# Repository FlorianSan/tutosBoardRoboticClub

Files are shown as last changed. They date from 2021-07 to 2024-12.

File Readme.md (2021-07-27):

# Carte tutos club Robot

Carte électronique pour apprendre les bases de l'électronique et de la programmation au nouveaux membres du club robotique.

Cette carte devrait être suffisamment compacte et pratique pour être emportée chez soi.

Sujets:

+ LEDs
+ boutons, pullups, ...
+ potentiomètre: analogique
+ PWM
+ UART
+ I2C
+ Encoder
+ Asservissement d'un moteur

Carte compatible Nucleo F411, F401RE. (et peut-être d'autres)

# Getting started

Le plus simple pour démarrer est d'installer VSCode, et l'extension PlateformIO.

Créer un projet pour la carte que vous utilisez (par exemple : ST Nucleo F401RE), avec le framwork Arduino.

Ajouter ceci au fichier `platformio.ini` pour activer l'UART6 qui va permettre de communiquer avec l'ATtiny1616 :

`build_flags = -D ENABLE_HWSERIAL6`

# Pinout

## Nucleo

| Pin | Signal |
|-----|---|
|PA0  |BTN1 (B1)  |
|PA1  |BTN2 (B2)  |
|PA4  |BUZZ |
|PA8  |Enc1A |
|PA9  |Enc1B |
|PA10 |Display_CLK|
|PA11 |UART6_TX |
|PA12 |UART6_RX |
|PA15 |MotB |
|PB0  |POT |
|PB1  |LED1 |
|PB4  |SERVO1 |
|PB5  |SERVO2 |
|PB6  |Enc2A |
|PB7  |Enc2B |
|PB8  |SCL1 |
|PB9  |SDA1 |
|PB10 |MotA |
|PB12 |Attiny_link|
|PC4  |Display_DIO|
|PC8  |LED2 |
|PC9  |INT_TCA |

Les jumpers JP1 et JP2 connectent respectivement une résistance de pullup et de pulldown aux signaux BTN1 et BTN2.

Afin d'utiliser les servomoteurs ou le moteur, il faut alimenter la carte par le connecteur jack DC en 12V (12V sur le connecteur central, GND sur l'extérieur), et régler le jumper JP5 de la nucleo (à côté du bouton RESET) sur "E5V".
La led D19 devrait s'allumer.

## TCA9554

| Pin | Signal  |
|-----|---|
|P0 |D4 |
|P1 |D5 |
|P2 |D6 |
|P3 |D7 |
|P4 |D17 |
|P5 |D18 |
|P6 |SW6 (B3) |
|P7 |SW7 (B4) |

SW5 permet de régler un bit d'adresse (A0).

SW4 permet de connecter ou pas les pullups sur SDA et SCL.

La broche INT est connectée sur la broche PC9 de la nucleo.

Les broches d'adresses A1 et A2 sont connectés à GND.

datasheet : [http://www.ti.com/lit/ds/symlink/tca9554.pdf](http://www.ti.com/lit/ds/symlink/tca9554.pdf)

## Display

L'afficheur 7segments 4 digits est commandé par un TM1637.

datasheet : [https://www.mcielectronics.cl/website_MCI/static/documents/Datasheet_TM1637.pdf](https://www.mcielectronics.cl/website_MCI/static/documents/Datasheet_TM1637.pdf)

## Driver moteur

Le driver moteur est un BD62120AEFJ.

datasheet : [https://docs.rs-online.com/a300/0900766b816747fb.pdf](https://docs.rs-online.com/a300/0900766b816747fb.pdf)

## ATtiny 1616

:warning: Si vous regardez ça, vous savez ce que vous faites !

| Pin | Signal |
|-----|---|
|PA0  |UPDI |
|PA2  |Attiny_link|
|PA4  |D10 |
|PA5  |D9 |
|PA6  |D8 |
|PA7  |D16 |
|PB0  |D11 |
|PB1  |D13 |
|PB2  |UART6_RX |
|PB3  |UART6_TX |
|PB4  |D14 |
|PB5  |D15 |
|PC0  |D12 |
|PC1  |AtPot |
|PC2  |AtLight |

:warning: UART6_RX et UART6_TX sont les signaux de la nucleo, qui correspondent donc respectivement à TX et RX de l'ATtiny.

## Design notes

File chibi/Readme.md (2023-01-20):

# ChibiOS example

Install the compiler, the debugger, and the stlink tools:

`sudo apt-get install gcc-arm-none-eabi gdb-multiarch stlink-tools`

Fetch ChibiOS and the STM32 pin data:

`git submodule update --init --recursive`

Build the firmware:

`make`

Flash the MCU:

`make flash`

The `ext/boardGen.pl` tool is extracted from https://github.com/alex31/chibios_enac_various_common.git.
It uses data from https://github.com/STMicroelectronics/STM32_open_pin_data to generate the `board.h` file from a short `board.cfg`.

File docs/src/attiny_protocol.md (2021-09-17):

# Attiny protocol

The Attiny1616 featured in the tuto board controls 9 leds, and has 2 inputs : a potentiometer and a phototransistor, acting as light sensor.

The protocol documented here allows you to interact with the Attiny.

Packets sent by the nucleo to the Attiny will be called **Tx packets**. Those sent by the Attiny to the nucleo will be called **Rx packets**.

## Message format

All messages have the same format :

<table>
<tr>
<td>STX</td>
<td>LEN</td>
<td>PAYLOAD[...]</td>
<td>CHK</td>
</tr>
</table>

**STX**  
Start of the packet. STX=0xFF.

**LEN**  
Byte size of the PAYLOAD and CHK field.

**PAYLOAD**  
See Tx packets and Rx Packets.

**CHK**  
Checksum for the packet.
CHK = ~(LEN + PAYLOAD[0] + … + PAYLOAD[N])

## Tx packets

Payload of Tx packets is made of a 1 byte instruction optionally followed by parameters.

<table>
<tr>
<td>STX</td>
<td>LEN</td>
<td>INSTRCTION</td>
<td>PARAM 1</td>
<td>...</td>
<td>PARAM N</td>
<td>CHK</td>
</tr>
</table>

The instructions are:

+ **PING**  
  Ping the Attiny.  
  + Value: **0x01**
  + Parameters: no parameters
  + Answer: PONG message.

+ **READ**  
  Request the values of *count* registers, starting at *address*.  
  + Value: **0x02**
  + Parameters: Address (1byte), count (1byte)
  + Answer: REG message.

+ **WRITE**  
  Write the *values* at registers starting at *address*. The register address is auto-incremented.  
  + Value: **0x03**
  + Parameters: address, value1, value2, …
  + Answer: no answer

## Rx packets
Payload of Rx packets is made of a 1 byte identifier optionally followed by data.

+ **PONG**
  + Value: 0x11
  + Data: no data

+ **REG**
  + Value: 0x12
  + Data: values

+ **CONTINUOUS**
  + Value: 0x13
  + Data: 2 bytes defined as follow:

<table>
<tr>
<td>data_id[1:0]</td>
<td bgcolor="gray">RESERVED</td>
<td>data[9:8]</td>
</tr>
<tr>
<td colspan="3" style="text-align:center">data[7:0]</td>
</tr>
</table>

Where data_id identify the nature of the data:

+ 0x0: potentiometer value
+ 0x1: light value
+ 0x2: leds status

The data itself spans over 10 bits for potentiometer and light values, and 9 bits for leds status.

## Registers description

|Name |Address|Access|
|---|---|---|
|POT_L  |0X00 |R |
|POT_H  |0X01 |R |
|LIGHT_L|0X02 |R |
|LIGHT_H|0X03 |R |
|LEDS_L |0X04 |RW |
|LEDS_H |0X05 |RW |
|MODE |0X06 |RW |

### POT

10 bits potentiometer value.

<div>
    <div style="width: 60px; float: left;">
        POT_H<br/>
        POT_L
    </div>
    <div>
        <table>
        <tr>
        <td bgcolor="gray">RESERVED</td>
        <td>POT[9:8]</td>
        </tr>
        <tr>
        <td colspan="2" style="text-align:center">POT[7:0]</td>
        </tr>
        </table>
     </div>
</div>

### LIGHT

10 bits light value.

<div>
    <div style="width: 60px; float: left;">
        LIGHT_H<br/>
        LIGHT_L
    </div>
    <div>
        <table>
        <tr>
        <td bgcolor="gray">RESERVED</td>
        <td>LIGHT[9:8]</td>
        </tr>
        <tr>
        <td colspan="2" style="text-align:center">LIGHT[7:0]</td>
        </tr>
        </table>
     </div>
</div>

### LEDS

State of the leds. 0 is OFF, 1 is ON.  
Default value: 0

<div>
    <div style="width: 60px; float: left;">
        LEDS_H<br/>
        LEDS_L
    </div>
    <div>
        <table>
        <tr>
        <td bgcolor="gray">RESERVED</td>
        <td>LEDS[8]</td>
        </tr>
        <tr>
        <td colspan="2" style="text-align:center">LEDS[7:0]</td>
        </tr>
        </table>
     </div>
</div>

### MODE

+ **POTC**: if set, the Attiny will send CONTINUOUS potentiometer data. **Default 0**.
+ **LIGHTC**: if set, the Attiny will send CONTINUOUS light data. **Default 0**.
+ **LEDSC**: if set, the Attiny will send CONTINUOUS leds data. **Default 0**.
+ **CFREQ**: frequency at which CONTINUOUS messages will be sent.
+ **LEDSMODE**: Leds command mode.

<table>
<tr>
<td>POTC</td>
<td>LIGHTC</td>
<td>LEDSC</td>
<td>CFREQ[1:0]</td>
<td>LEDSMODE[2:0]</td>
</table>

**bitfields values:**

<div style="display:flex;">
    <div style="flex:1;">
        CFREQ[1:0]   
        <ul>
        <li>0x0: 50ms (20Hz)</li>
        <li>0x1: 100ms (10Hz) <strong>default</strong></li>
        <li>0x2: 200ms (5Hz)</li>
        <li>0x3: 500ms (2Hz)</li>
        </ul>
    </div>
    <div style="flex:1">
        LEDSMODE[2:0]  
        <ul>
        <li>0x0: MANUAL: write to the LEDS register to command the leds.</li>
        <li>0x1: Pot value: leds reflect potentiometer value. <strong>default</strong></li>
        <li>0x2: Light value: leds reflect light value.</li>
        <li>0x3: Pot speed: not implemented</li>
        <li>0x4: Light speed: not implemented</li>
        </ul>
     </div>
</div>

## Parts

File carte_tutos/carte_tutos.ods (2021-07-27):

Qty | Reference(s) | Value | LibPart | Footprint | Price | Total
1 | BZ1 | Buzzer | Device:Buzzer | Buzzer_Beeper:MagneticBuzzer_ProSignal_ABT-410-RC | 0.4 | 0.4
2 | C1, C2 | 100p | Device:C | Capacitor_SMD:C_0603_1608Metric_Pad1.08x0.95mm_HandSolder | 0.04 | 0.08
4 | C3, C5, C7, C8 | 100n | Device:C | Capacitor_SMD:C_0603_1608Metric_Pad1.08x0.95mm_HandSolder | 0.04 | 0.16
2 | C4, C6 | 100u | Device:C | Capacitor_Tantalum_SMD:CP_EIA-6032-28_Kemet-C_Pad2.25x2.35mm_HandSolder | 0.8 | 1.6
18 | D1, D2, D4, D5, D6, D7, D8, D9, D10, D11, D12, D13, D14, D15, D16, D17, D18, D19 | LED | Device:LED | LED_SMD:LED_0603_1608Metric_Pad1.05x0.95mm_HandSolder | 0.07 | 1.26
1 | D3 | D_Schottky | Device:D_Schottky | Diode_SMD:D_SOD-123F | 0.364 | 0.364 | https://fr.rs-online.com/web/p/redresseurs-et-diodes-schottky/0485521
4 | J1, J2, J6, J8 | Conn_01x03_Male | Connector:Conn_01x03_Male | Connector_PinHeader_2.54mm:PinHeader_1x03_P2.54mm_Vertical | 0.1 | 0.4
1 | J3 | Barrel_Jack | Connector:Barrel_Jack |  | 0.353 | 0.353 | https://fr.rs-online.com/web/p/connecteurs-d-alimentation-dc/0448376
1 | J4 | Conn_01x04_Male | Connector:Conn_01x04_Male | Connector_PinHeader_2.54mm:PinHeader_1x04_P2.54mm_Vertical | 0.1 | 0.1
2 | J5, J7 | Conn_01x02_Male | Connector:Conn_01x02_Male | Connector_PinHeader_2.54mm:PinHeader_1x02_P2.54mm_Vertical | 0.1 | 0.2
2 | JP1, JP2 | Jumper | Device:Jumper | Connector_PinHeader_2.54mm:PinHeader_1x02_P2.54mm_Vertical | 0.1 | 0.2
1 | Q1 | SFH_3410-Z | tutoLib:SFH_3410-Z | tutoFp:SFH_3410 | 0.4 | 0.4 | https://fr.rs-online.com/web/p/phototransistors/0539864
10 | R1, R4, R5, R7, R9, R13, R14, R20, R21, R39 | 100 | Device:R_Small | Resistor_SMD:R_0603_1608Metric_Pad0.98x0.95mm_HandSolder | 0.02 | 0.2
17 | R2, R3, R19, R22, R27, R28, R29, R30, R31, R32, R33, R34, R35, R36, R37, R40, R41 | 390 | Device:R | Resistor_SMD:R_0603_1608Metric_Pad0.98x0.95mm_HandSolder | 0.02 | 0.34
6 | R6, R8, R11, R12, R17, R26 | 10k | Device:R | Resistor_SMD:R_0603_1608Metric_Pad0.98x0.95mm_HandSolder | 0.02 | 0.12
1 | R10 | 220 | Device:R | Resistor_SMD:R_0603_1608Metric_Pad0.98x0.95mm_HandSolder | 0.02 | 0.02
2 | R15, R16 | 2.2K | Device:R | Resistor_SMD:R_0603_1608Metric_Pad0.98x0.95mm_HandSolder | 0.02 | 0.04
1 | R18 | 1k | Device:R | Resistor_SMD:R_0603_1608Metric_Pad0.98x0.95mm_HandSolder | 0.02 | 0.02
1 | R23 | 2k | Device:R | Resistor_SMD:R_0603_1608Metric_Pad0.98x0.95mm_HandSolder | 0.02 | 0.02
1 | R38 | 470 | Device:R_Small | Resistor_SMD:R_0603_1608Metric_Pad0.98x0.95mm_HandSolder | 0.02 | 0.02
2 | RV1, RV2 | R_POT | Device:R_POT | Potentiometer_THT:Potentiometer_Bourns_PTV09A-1_Single_Vertical | 0.73 | 1.46 | https://fr.rs-online.com/web/p/potentiometres/1814488
1 | SW1 | Rotary_Encoder_Switch | Device:Rotary_Encoder | Rotary_Encoder:RotaryEncoder_Alps_EC12E_Vertical_H20mm | 0.77 | 0.77 | https://fr.rs-online.com/web/p/encodeurs-rotatifs-mecaniques/6234221
4 | SW2, SW3, SW6, SW7 | SW_Push | Switch:SW_Push | Button_Switch_SMD:SW_SPST_EVQPE1 | 0.493 | 1.972 | https://fr.rs-online.com/web/p/interrupteurs-tactiles/3786325/
1 | SW4 | SW_DIP_x02 | Switch:SW_DIP_x02 | Button_Switch_THT:SW_DIP_SPSTx02_Slide_9.78x7.26mm_W7.62mm_P2.54mm | 0.4 | 0.4
1 | SW5 | SW_SPDT | Switch:SW_SPDT | Button_Switch_SMD:SW_SPDT_PCM12 | 0.94 | 0.94
1 | U1 | TM1637 | tutoLib:TM1637 | Package_SO:SOP-20_7.5x12.8mm_P1.27mm | 1 | 1
1 | U2 | CA56-12EWA | Display_Character:CA56-12EWA | Display_7Segment:CA56-12EWA | 0.6 | 0.6
1 | U3 | BD62120AEFJ | tutoLib:BD62120AEFJ | Package_SO:HTSOP-8-1EP_3.9x4.9mm_P1.27mm_EP2.4x3.2mm | 2.525 | 2.525 | https://fr.rs-online.com/web/p/drivers-de-moteur/1780653
1 | U4 | NUCLEO64-F411RE | MCU_Module:NUCLEO64-F411RE | Module:ST_Morpho_Connector_144_STLink | 14.87 | 14.87 | https://fr.rs-online.com/web/p/outils-de-developpement-pour-microcontroleurs/8029425/
1 | U5 | TCA9554DBQ | Interface_Expansion:TCA9554DBQ | Package_SO:SSOP-16_3.9x4.9mm_P0.635mm | 1.742 | 1.742 | https://fr.rs-online.com/web/p/expandeurs-e-s/1330708/
1 | U6 | ATtiny1616-S | MCU_Microchip_ATtiny:ATtiny1616-S | Package_SO:SOIC-20W_7.5x12.8mm_P1.27mm | 1 | 1 | https://fr.rs-online.com/web/p/microcontroleurs/1936207
1 |  | Jack mâle |  |  | 2.17 | 2.17 | https://fr.rs-online.com/web/p/connecteurs-d-alimentation-dc/1389405
1 |  | PCB |  |  | 5 | 5
 |  |  |  |  |  | 40.746

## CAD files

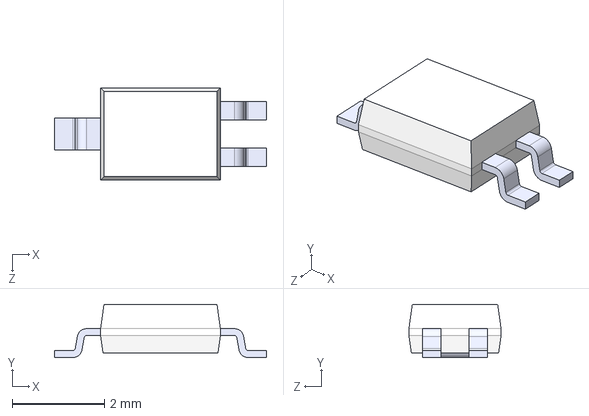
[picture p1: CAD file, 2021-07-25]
carte_tutos/SFH_3410-Z.step
4.60 x 1.15 x 2.00 mm

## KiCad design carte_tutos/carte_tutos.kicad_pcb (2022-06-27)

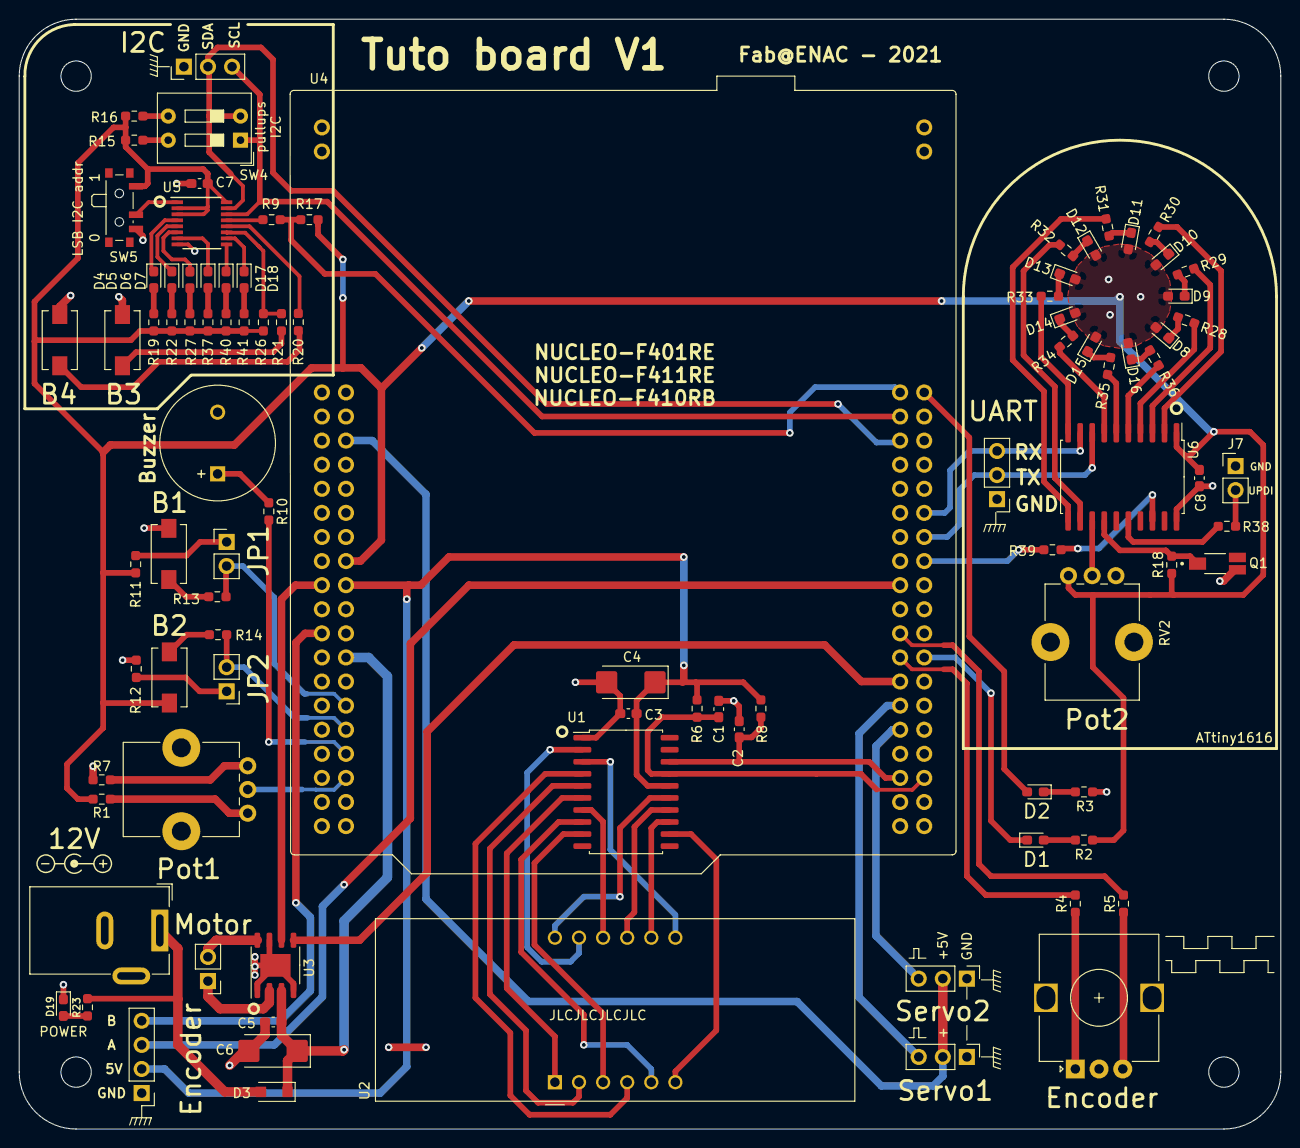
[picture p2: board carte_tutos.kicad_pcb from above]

Board: 2 copper layers, 133.0 x 117.0 mm, 93 parts (0 on the bottom side), 97 nets.

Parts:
BZ1: Buzzer; MagneticBuzzer_ProSignal_ABT-410-RC
C1, C2: 100p; C_0603_1608Metric_Pad1.08x0.95mm_HandSolder
C3, C5, C7, C8: 100n; C_0603_1608Metric_Pad1.08x0.95mm_HandSolder
C4, C6: 100u; CP_EIA-6032-28_Kemet-C_Pad2.25x2.35mm_HandSolder
D1, D2, D4, D5, D6, D7, D8, D9, D10, D11, D12, D13, D14, D15, D16, D17, D18, D19: LED; LED_0603_1608Metric_Pad1.05x0.95mm_HandSolder
D3: D_Schottky; D_SOD-123F
J1, J2, J6, J8: Conn_01x03_Male; PinHeader_1x03_P2.54mm_Vertical
J3: Barrel_Jack; BarrelJack_Wuerth_6941xx301002
J4: Conn_01x04_Male; PinHeader_1x04_P2.54mm_Vertical
J5, J7: Conn_01x02_Male; PinHeader_1x02_P2.54mm_Vertical
JP1, JP2: Jumper; PinHeader_1x02_P2.54mm_Vertical
Q1: SFH_3410-Z; SFH_3410
R1, R4, R5, R7, R9, R13, R14, R20, R21, R39: 100; R_0603_1608Metric_Pad0.98x0.95mm_HandSolder
R2, R3, R19, R22, R27, R28, R29, R30, R31, R32, R33, R34, R35, R36, R37, R40, R41: 390; R_0603_1608Metric_Pad0.98x0.95mm_HandSolder
R6, R8, R11, R12, R17, R26: 10k; R_0603_1608Metric_Pad0.98x0.95mm_HandSolder
R10: 220; R_0603_1608Metric_Pad0.98x0.95mm_HandSolder
R15, R16: 2.2K; R_0603_1608Metric_Pad0.98x0.95mm_HandSolder
R18: 1k; R_0603_1608Metric_Pad0.98x0.95mm_HandSolder
R23: 2k; R_0603_1608Metric_Pad0.98x0.95mm_HandSolder
R38: 470; R_0603_1608Metric_Pad0.98x0.95mm_HandSolder
RV1, RV2: R_POT; Potentiometer_Bourns_PTV09A-1_Single_Vertical
SW1: Rotary_Encoder_Switch; RotaryEncoder_Alps_EC12E_Vertical_H20mm
SW2, SW3, SW6, SW7: SW_Push; SW_SPST_EVQPE1
SW4: SW_DIP_x02; SW_DIP_SPSTx02_Slide_9.78x7.26mm_W7.62mm_P2.54mm
SW5: SW_SPDT; SW_SPDT_PCM12
U1: TM1637; SOP-20_7.5x12.8mm_P1.27mm
U2: CA56-12EWA
U3: BD62120AEFJ; HTSOP-8-1EP_3.9x4.9mm_P1.27mm_EP2.4x3.2mm
U4: NUCLEO64-F411RE; ST_Morpho_Connector_64_STLink
U5: TCA9554DBQ; SSOP-16_3.9x4.9mm_P0.635mm
U6: ATtiny1616-S; SOIC-20W_7.5x12.8mm_P1.27mm

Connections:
+3V3: C7.1, C8.1, D8.2, D9.2, D10.2, D11.2, D12.2, D13.2, D14.2, D15.2, D16.2, R1.2, R2.2, R11.2, R15.1, R16.1, R17.1, R18.1, R19.1, R22.1, R26.1, R27.1, R37.1, R40.1, R41.1, RV2.1, SW3.1, SW5.1, U4.16, U5.2, U5.3, U5.16, U6.1
+5V: C3.1, C4.1, J4.2, R6.2, R8.2, U1.16, U4.18
+5VP: J1.2, J2.2, U4.6
+12V: C5.1, C6.1, D3.1, U3.3, U4.24
/AtLed1: R28.1, U6.4
/AtLed2: R29.1, U6.3
/AtLed3: R30.1, U6.2
/AtLed4: R31.1, U6.11
/AtLed5: R32.1, U6.12
/AtLed6: R33.1, U6.10
/AtLed7: R34.1, U6.7
/AtLed8: R35.1, U6.6
/AtLed9: R36.1, U6.5
/AtLight: Q1.1, R18.2, U6.14
/AtPot: RV2.2, U6.13
/GRID1: U1.15, U2.12
/GRID2: U1.14, U2.9
/GRID3: U1.13, U2.8
/GRID4: U1.12, U2.6
/UPDI: J7.2, R38.1
Attiny_link: R39.1, U4.54
BTN1: JP1.2, R13.1, U4.28
BTN2: JP2.2, R14.1, U4.30
BUZZ: R10.2, U4.32
Display_CLK: C2.2, R8.1, U1.18, U4.71
Display_DIO: C1.2, R6.1, U1.17, U4.72
Enc1A: R4.2, U4.61
Enc1B: R5.2, U4.59
Enc2A: J4.3, U4.55
Enc2B: J4.4, U4.21
GND: BZ1.2, C1.1, C2.1, C3.2, C4.2, C5.2, C6.2, C7.2, C8.2, D19.1, J1.1, J2.1, J3.2, J3.3, J4.1, J6.1, J7.1, J8.1, Q1.3, R3.2, R7.1, R12.2, RV2.3, SW1.C, SW2.1, SW5.3, SW6.2, SW7.2, U1.1, U3.1, U3.4, U3.7, U3.9, U4.8, U4.19, U4.20, U4.22, U4.47, U4.58, U4.70, U4.77, U4.78, U4.79, U4.80, U5.8, U6.20
INT_TCA: R9.2, R17.2, U4.39
LED1: D1.1, U4.62
LED2: D2.2, U4.40
MotA: U3.5, U4.63
MotB: U3.6, U4.17
unnamed: BZ1.1, R10.1
unnamed: D1.2, R2.1
unnamed: D2.1, R3.1
unnamed: D3.2, J3.1, R23.2
unnamed: D4.1, U5.4
unnamed: D4.2, R19.2
unnamed: D5.1, U5.5
unnamed: D5.2, R22.2
unnamed: D6.1, U5.6
unnamed: D6.2, R27.2
unnamed: D7.1, U5.7
unnamed: D7.2, R37.2
unnamed: D8.1, R28.2
unnamed: D9.1, R29.2
unnamed: D10.1, R30.2
unnamed: D11.1, R31.2
unnamed: D12.1, R32.2
unnamed: D13.1, R33.2
unnamed: D14.1, R34.2
unnamed: D15.1, R35.2
unnamed: D16.1, R36.2
unnamed: D17.1, U5.9
unnamed: D17.2, R40.2
unnamed: D18.1, U5.10
unnamed: D18.2, R41.2
unnamed: D19.2, R23.1
unnamed: J5.1, U3.2
unnamed: J5.2, U3.8
unnamed: JP1.1, R11.1
unnamed: JP2.1, R12.1
unnamed: R1.1, RV1.3
unnamed: R4.1, SW1.A
unnamed: R5.1, SW1.B
unnamed: R7.2, RV1.1
unnamed: R9.1, U5.13
unnamed: R13.2, SW2.2
unnamed: R14.2, SW3.2
unnamed: R15.2, SW4.4
unnamed: R16.2, SW4.3
unnamed: R20.1, SW7.1
unnamed: R20.2, U5.12
unnamed: R21.1, SW6.1
unnamed: R21.2, R26.2, U5.11
unnamed: R38.2, U6.16
unnamed: R39.2, U6.18
unnamed: SW5.2, U5.1
unnamed: U1.2, U2.11
unnamed: U1.3, U2.7
unnamed: U1.4, U2.4
unnamed: U1.5, U2.2
unnamed: U1.6, U2.1
unnamed: U1.7, U2.10
unnamed: U1.8, U2.5
unnamed: U1.9, U2.3
POT: RV1.2, U4.34
SCL1: J6.3, SW4.1, U4.41, U5.14
SDA1: J6.2, SW4.2, U4.43, U5.15
SERVO1: J1.3, U4.65
SERVO2: J2.3, U4.67
UART6_RX: J8.3, U4.50, U6.9
UART6_TX: J8.2, U4.52, U6.8

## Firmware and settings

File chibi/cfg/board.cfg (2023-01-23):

MCU_MODEL = STM32F401R(D-E)Tx
CHIBIOS_VERSION = 3.0

HEADER
/*
 * Board identifier.
 */
#define BOARD_TUTO_ENAC_ROBOTIQUE
#define BOARD_NAME                  "Tuto board ENAC Robotique V1"

/*
 * Board oscillators-related settings.
 * NOTE: LSE not fitted.
 */
#if !defined(STM32_LSECLK)
#define STM32_LSECLK                0U
#endif

#define STM32_LSEDRV                (3U << 3U)

#if !defined(STM32_HSECLK)
#define STM32_HSECLK                8000000U
#endif
#define STM32_HSE_BYPASS

/*
 * Board voltages.
 * Required for performance limits calculation.
 */
#define STM32_VDD                   300U

/*
 * MCU type as defined in the ST header.
 */
#define STM32F401xE

CONFIG


# PIN NAME PERIPH_TYPE AF_NUMBER or
# PIN NAME FUNCTION PP_or_OPENDRAIN PIN_SPEED PULL_RESISTOR INITIAL_LEVEL AF_NUMBER
# SPEED : SPEED_VERYLOW, SPEED_LOW, SPEED_MEDIUM, SPEED_HIGH
#
# DEFAULT AND SYS
# 
# 'SYS' => ['ALTERNATE', 'PUSHPULL', 'SPEED_HIGH', 'FLOATING', 'LEVEL_HIGH'],
# 'ADC' => ['ANALOG', 'PUSHPULL', 'SPEED_HIGH', 'FLOATING', 'LEVEL_LOW'],
# 'PWM' => ['ALTERNATE', 'PUSHPULL', 'SPEED_HIGH', 'FLOATING', 'LEVEL_LOW'],
# 'ICU' => ['ALTERNATE', 'PUSHPULL', 'SPEED_HIGH', 'FLOATING', 'LEVEL_HIGH'],
# 'I2C' => ['ALTERNATE', 'OPENDRAIN', 'SPEED_HIGH', 'PULLUP', 'LEVEL_HIGH'],
# 'SPI' => ['ALTERNATE', 'PUSHPULL', 'SPEED_HIGH', 'FLOATING', 'LEVEL_HIGH'],
# 'UART' => ['ALTERNATE', 'PUSHPULL', 'SPEED_HIGH', 'PULLUP', 'LEVEL_HIGH'],
# 'OTG' => ['ALTERNATE', 'PUSHPULL', 'SPEED_HIGH', 'FLOATING', 'LEVEL_HIGH'],
# 'ETH' => ['ALTERNATE', 'PUSHPULL', 'SPEED_HIGH', 'FLOATING', 'LEVEL_HIGH'],
# 'FSMC' => ['ALTERNATE', 'PUSHPULL', 'SPEED_HIGH', 'FLOATING', 'LEVEL_HIGH'],
# 'SDIO' => ['ALTERNATE', 'PUSHPULL', 'SPEED_HIGH', 'PULLUP', 'LEVEL_HIGH'],
# 'SDIOCK' => ['ALTERNATE', 'PUSHPULL', 'SPEED_HIGH', 'FLOATING', 'LEVEL_HIGH'],
# 'CAN' => ['ALTERNATE', 'PUSHPULL', 'SPEED_HIGH', 'FLOATING', 'LEVEL_HIGH'],
# 'DCMI' => ['ALTERNATE', 'PUSHPULL', 'SPEED_HIGH', 'FLOATING', 'LEVEL_HIGH'],
# 'LED' => ['OUTPUT', 'PUSHPULL', 'SPEED_VERYLOW', 'FLOATING', 'LEVEL_LOW'],
# 'PASSIVE' => ['INPUT', 'PUSHPULL', 'SPEED_VERYLOW', 'FLOATING', 'LEVEL_LOW']);


# SYSTEM
PA13    SWDIO       SYS     AF:SYS_JTMS-SWDIO
PA14    SWCLK       SYS     AF:SYS_JTCK-SWCLK
#PB03    SWO         SYS     AF:SYS_JTDO-SWO


#PC14    OSC32_IN    SYS RCC_OSC32_IN 
#PC15    OSC32_OUT   SYS RCC_OSC32_OUT
PH00    OSC_IN      SYS RCC_OSC_IN
PH01    OSC_OUT     SYS RCC_OSC_OUT


#DEFAULT
DEFAULT                 INPUT   PUSHPULL SPEED_VERYLOW PULLDOWN LEVEL_LOW  AF0

# LEDS
PA05    LED_GREEN   LED
PC08    LED2        LED
PB01    LED1        LED

# BUTTONS
PC13    BUTTON      INPUT PULLUP
PA00    BTN1        INPUT PULLUP
PA01    BTN2        INPUT PULLUP

# UART debug
PA02    USART2_TX   UART    AF:USART2_TX
PA03    USART2_RX   UART    AF:USART2_RX

# UART Attiny
PA11    USART6_TX   UART    AF:USART6_TX
PA12    USART6_RX   UART    AF:USART6_RX

# I2C
PB08	I2C_SCL		I2C	    AF:I2C1_SCL
PB09	I2C_SDA		I2C	    AF:I2C1_SDA

# TCA interrupt input
PC09    TCA_INT     INPUT   FLOATING

# potentiometre
PB00    POTAR       ADC     ADC1_IN8

# servos
PB04    SERVO1      PWM     AF:TIM3_CH1
PB05    SERVO2      PWM     AF:TIM3_CH2

# motor
PB10    MOTA        PWM     AF:TIM2_CH3
PA15    MOTB        PWM     AF:TIM2_CH1

# encoder button
PA08    ENCB_A      ALTERNATE   PUSHPULL  SPEED_VERYLOW  PULLUP AF:TIM1_CH1
PA09    ENCB_B      ALTERNATE   PUSHPULL  SPEED_VERYLOW  PULLUP AF:TIM1_CH2

# encoder motor
PB06    ENCM_A      ALTERNATE   PUSHPULL  SPEED_VERYLOW  PULLUP AF:TIM4_CH1
PB07    ENCM_B      ALTERNATE   PUSHPULL  SPEED_VERYLOW  PULLUP AF:TIM4_CH2

# TM1637 Display
PA10    DISPLAY_CLK OUTPUT  OPENDRAIN   SPEED_HIGH  FLOATING    LEVEL_HIGH
PC04    DISPLAY_IO  OUTPUT  OPENDRAIN   SPEED_HIGH  FLOATING    LEVEL_HIGH

#PA04 BUZZER    no timer !
#PB12 ???

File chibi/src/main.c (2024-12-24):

/*
    ChibiOS - Copyright (C) 2006..2018 Giovanni Di Sirio

    Licensed under the Apache License, Version 2.0 (the "License");
    you may not use this file except in compliance with the License.
    You may obtain a copy of the License at

        http://www.apache.org/licenses/LICENSE-2.0

    Unless required by applicable law or agreed to in writing, software
    distributed under the License is distributed on an "AS IS" BASIS,
    WITHOUT WARRANTIES OR CONDITIONS OF ANY KIND, either express or implied.
    See the License for the specific language governing permissions and
    limitations under the License.
*/

#include "ch.h"
#include "hal.h"
#include "rt_test_root.h"
#include "oslib_test_root.h"


static const SerialConfig serialConfig =  {
  115200,
  0,
  USART_CR2_STOP1_BITS | USART_CR2_LINEN,
  0
};



/*
 * Green LED blinker thread, times are in milliseconds.
 */
static THD_WORKING_AREA(waThread1, 128);
static THD_FUNCTION(Thread1, arg) {

  (void)arg;
  chRegSetThreadName("blinker");
  while (true) {
    // palClearLine(LINE_LED_GREEN);
    // chThdSleepMilliseconds(500);
    // palSetLine(LINE_LED_GREEN);
    // chThdSleepMilliseconds(500);
    void pin_toggle(void);
    pin_toggle();
    chThdSleepMilliseconds(500);
  }
}

/*
 * Application entry point.
 */
int main(void) {

  /*
   * System initializations.
   * - HAL initialization, this also initializes the configured device drivers
   *   and performs the board-specific initializations.
   * - Kernel initialization, the main() function becomes a thread and the
   *   RTOS is active.
   */
  halInit();
  chSysInit();
  

  /*
   * Activates the serial driver 2 using the driver default configuration.
   */
  sdStart(&SD2, &serialConfig);

  void pin_cfg(void);
  pin_cfg();

  /*
   * Creates the blinker thread.
   */
  chThdCreateStatic(waThread1, sizeof(waThread1), NORMALPRIO + 1, Thread1, NULL);

  /*
   * Normal main() thread activity, in this demo it does nothing except
   * sleeping in a loop and check the button state.
   */
  while (true) {
    if (!palReadLine(LINE_BUTTON)) {
      test_execute((BaseSequentialStream *)&SD2, &rt_test_suite);
      test_execute((BaseSequentialStream *)&SD2, &oslib_test_suite);
    }
    chThdSleepMilliseconds(500);
  }
}

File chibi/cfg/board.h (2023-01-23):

/*
    ChibiOS - Copyright (C) 2006..2015 Giovanni Di Sirio

    Licensed under the Apache License, Version 2.0 (the "License");
    you may not use this file except in compliance with the License.
    You may obtain a copy of the License at

        http://www.apache.org/licenses/LICENSE-2.0

    Unless required by applicable law or agreed to in writing, software
    distributed under the License is distributed on an "AS IS" BASIS,
    WITHOUT WARRANTIES OR CONDITIONS OF ANY KIND, either express or implied.
    See the License for the specific language governing permissions and
    limitations under the License.
*/

#pragma once

/*
 * Board identifier.
 */
#define BOARD_TUTO_ENAC_ROBOTIQUE
#define BOARD_NAME                  "Tuto board ENAC Robotique V1"

/*
 * Board oscillators-related settings.
 * NOTE: LSE not fitted.
 */
#if !defined(STM32_LSECLK)
#define STM32_LSECLK                0U
#endif

#define STM32_LSEDRV                (3U << 3U)

#if !defined(STM32_HSECLK)
#define STM32_HSECLK                8000000U
#endif
#define STM32_HSE_BYPASS

/*
 * Board voltages.
 * Required for performance limits calculation.
 */
#define STM32_VDD                   300U

/*
 * MCU type as defined in the ST header.
 */
#define STM32F401xE

/*
 * IO pins assignments.
 */
#define	PA00_BTN1                      0U
#define	PA01_BTN2                      1U
#define	PA02_USART2_TX                 2U
#define	PA03_USART2_RX                 3U
#define	PA04                           4U
#define	PA05_LED_GREEN                 5U
#define	PA06                           6U
#define	PA07                           7U
#define	PA08_ENCB_A                    8U
#define	PA09_ENCB_B                    9U
#define	PA10_DISPLAY_CLK               10U
#define	PA11_USART6_TX                 11U
#define	PA12_USART6_RX                 12U
#define	PA13_SWDIO                     13U
#define	PA14_SWCLK                     14U
#define	PA15_MOTB                      15U

#define	PB00_POTAR                     0U
#define	PB01_LED1                      1U
#define	PB02                           2U
#define	PB03                           3U
#define	PB04_SERVO1                    4U
#define	PB05_SERVO2                    5U
#define	PB06_ENCM_A                    6U
#define	PB07_ENCM_B                    7U
#define	PB08_I2C_SCL                   8U
#define	PB09_I2C_SDA                   9U
#define	PB10_MOTA                      10U
#define	PB11                           11U
#define	PB12                           12U
#define	PB13                           13U
#define	PB14                           14U
#define	PB15                           15U

#define	PC00                           0U
#define	PC01                           1U
#define	PC02                           2U
#define	PC03                           3U
#define	PC04_DISPLAY_IO                4U
#define	PC05                           5U
#define	PC06                           6U
#define	PC07                           7U
#define	PC08_LED2                      8U
#define	PC09_TCA_INT                   9U
#define	PC10                           10U
#define	PC11                           11U
#define	PC12                           12U
#define	PC13_BUTTON                    13U
#define	PC14                           14U
#define	PC15                           15U

#define	PD00                           0U
#define	PD01                           1U
#define	PD02                           2U
#define	PD03                           3U
#define	PD04                           4U
#define	PD05                           5U
#define	PD06                           6U
#define	PD07                           7U
#define	PD08                           8U
#define	PD09                           9U
#define	PD10                           10U
#define	PD11                           11U
#define	PD12                           12U
#define	PD13                           13U
#define	PD14                           14U
#define	PD15                           15U

#define	PE00                           0U
#define	PE01                           1U
#define	PE02                           2U
#define	PE03                           3U
#define	PE04                           4U
#define	PE05                           5U
#define	PE06                           6U
#define	PE07                           7U
#define	PE08                           8U
#define	PE09                           9U
#define	PE10                           10U
#define	PE11                           11U
#define	PE12                           12U
#define	PE13                           13U
#define	PE14                           14U
#define	PE15                           15U
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

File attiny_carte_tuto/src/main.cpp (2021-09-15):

#include <Arduino.h>
#include "adc.h"
#include "tutrocol.h"
#include "hard_interface.h"
#include "registers.h"

uint32_t continuous_time;

void setup() {
  leds_init();
  ADC1_init(ADC_MUXPOS_AIN7_gc);
  registers_init();
  Serial.begin(115200);
  tutrocol_init();
}

void loop() {
  tutrocol_recv();
  periodic_tasks();

  uint8_t cfreq = getRegister(MODE) & MODE_CFREQ_Mask;
  uint32_t continuous_period;
  switch (cfreq) {
    case MODE_CFREQ_50MS:
      continuous_period = 50;
      break;
    case MODE_CFREQ_100MS:
      continuous_period = 100;
      break;
    case MODE_CFREQ_200MS:
      continuous_period = 200;
      break;
    case MODE_CFREQ_500MS:
      continuous_period = 500;
      break;
    default:
      continuous_period = 1000;
  }

  if(millis() - continuous_time > continuous_period) {
    sendContinuous();
    continuous_time = millis();
  }
}

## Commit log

2021-07-23 Initial commit.
    [carte_tutos.kicad_pcb, carte_tutos.sch]
2021-07-23 Add ATtiny1616.
    [carte_tutos.sch]
2021-07-25 Add project libs, schematic almost done.
    [carte_tutos.sch]
2021-07-25 Fix ERC warnings.
    [carte_tutos.sch]
2021-07-25 Associate some footprints.
    [carte_tutos.sch]
2021-07-25 Add decoupling capacitor, and associate footprints
    [carte_tutos.sch]
2021-07-25 More footprint assignments.
    [SFH_3410-Z.step, carte_tutos.sch]
2021-07-25 Remove touch sensors.
    [carte_tutos.sch]
2021-07-25 Add BOM
    [carte_tutos.csv]
2021-07-25 Barrel jack & cleaning.
    [carte_tutos.sch]
2021-07-25 Fix nucleo footprint.
    [carte_tutos.sch]
2021-07-25 begin PCB
    [carte_tutos.kicad_pcb]
2021-07-26 More layout, and small schematic edits.
    [carte_tutos.kicad_pcb, carte_tutos.sch]
2021-07-26 Layout almost complete.
    [carte_tutos.csv, carte_tutos.kicad_pcb, carte_tutos.sch]
2021-07-26 Finish layout.
    [carte_tutos.kicad_pcb]
2021-07-26 Nucleo: reduce courtyard.
    [carte_tutos.kicad_pcb]
2021-07-27 More silk, and add power led.
    [carte_tutos.kicad_pcb, carte_tutos.sch]
2021-07-27 Update cubMx, Update BOM
    [carte_tutos.csv, carte_tutos.ods]
2021-07-27 Improve Silk.
    [carte_tutos.kicad_pcb]
2021-07-30 Fix unrouted track.
    [carte_tutos.kicad_pcb]
2021-09-15 [ATtiny] Fix some errors.
    [tutrocol.cpp]
2022-06-27 WIP? Will be cleaned up!
    [carte_tutos.kicad_pcb, carte_tutos.sch]
2023-01-20 Begin chibiOs example.
    [board.cfg]
2023-01-23 [ChibiOS] Improve board.cfg
    [board.cfg]
2023-01-23 Add schematics.
2024-12-24 Toggle led with rust
